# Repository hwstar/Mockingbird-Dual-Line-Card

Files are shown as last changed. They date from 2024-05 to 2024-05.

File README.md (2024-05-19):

# Mockingbird-Dual-Lane-Card
A dual subscriber line card for the Mockingbird Telephone Exchange

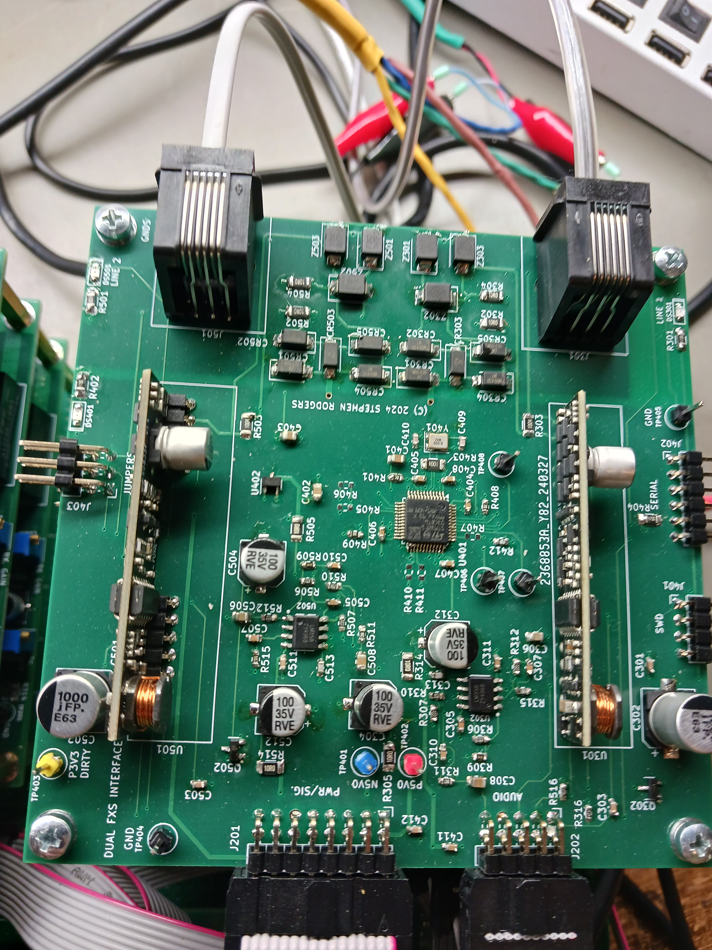
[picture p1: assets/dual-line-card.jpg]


An interface card design for the Mockingbird Telephone Exchange. 

Features: 
* Provides two subscriber line interfaces.
* STM32F103C8T6 microcontroller.
* Accessed from the Main Microcontroller over I2C
* ATTEN signal to main microcontroller to tell it when there is an event to service.
* Audio bandpass filter for the received audio.
* Uses one R-TONE KS0835 SLIC module for each telephone line interface.
* Analog RX audio output, and TX audio input.
* Designed n KiCAD 8.0.

The main project website is on hackaday.io here: https://hackaday.io/project/196044-mockingbird-telephone-exchange

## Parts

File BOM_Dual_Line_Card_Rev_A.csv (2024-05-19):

Item | Part Number | Qty | Reference(s) | Title/Description | Value on Schematic | Manufacturer | Manufacturer Part Number | Footprint
1 | 800063-104 | 15 | C301,C303,C305,C311,C404-C408,C411,C412,C501,C503,C505,C511 | CAP,0603,0.1u,50V,X7R | 0.1u | Kyocera AVX | 06035C104KAT2A | C_0603_1608Metric
1 | 800063-104 | 15 | C301,C303,C305,C311,C404-C408,C411,C412,C501,C503,C505,C511 | CAP,0603,0.1u,50V,X7R | 0.1u | Yageo | CC0603KRX7R9BB104 | C_0603_1608Metric
1 | 800063-104 | 15 | C301,C303,C305,C311,C404-C408,C411,C412,C501,C503,C505,C511 | CAP,0603,0.1u,50V,X7R | 0.1u | LCSC | C14663 | C_0603_1608Metric
2 | 800439-108 | 2 | C302,C502 | CAP,ALUM ELECT,1000UF,6.3V,80 MILLIOHM, 8MM | 1000u | LCSC | C401739 | CP_Elec_8x10.5
2 | 800439-108 | 2 | C302,C502 | CAP,ALUM ELECT,1000UF,6.3V,80 MILLIOHM, 8MM | 1000u | Panasonic | EEEP0J102AP | CP_Elec_8x10.5
3 | 800421-107 | 4 | C304,C312,C504,C512 | CAP,ALUM_ELECT,100uF,35V,ESR 600mOHM,6.3MM,2000 HR | 100u | LCSC | C2836437 | CP_Elec_6.3x7.7
3 | 800421-107 | 4 | C304,C312,C504,C512 | CAP,ALUM_ELECT,100uF,35V,ESR 600mOHM,6.3MM,2000 HR | 100u | KNSCHA | RVE100UF35V67RV0072 | CP_Elec_6.3x7.7
4 | 800423-224 | 2 | C306,C506 | CAP,0805,0.22UF,50V,5%,X7R | 0.22u | Yageo | CC0805JKX7R9BB224 | C_0805_2012Metric
4 | 800423-224 | 2 | C306,C506 | CAP,0805,0.22UF,50V,5%,X7R | 0.22u | LCSC | C520076 | C_0805_2012Metric
5 | 800422-154 | 2 | C307,C507 | CAP,0603,0.15UF,50V,5%,X7R | 0.15u | Yageo | CC0603JRX7R9BB154 | C_0603_1608Metric
5 | 800422-154 | 2 | C307,C507 | CAP,0603,0.15UF,50V,5%,X7R | 0.15u | LCSC | C519580 | C_0603_1608Metric
6 | 800003-106 | 3 | C308,C402,C508 | CAP,0805,10u,25V,X5R | 10u | Murata Electronics | GRM21BR61E106KA73L | C_0805_2012Metric
6 | 800003-106 | 3 | C308,C402,C508 | CAP,0805,10u,25V,X5R | 10u | Samsung Electromechanics | CL21A106KAYNNNE | C_0805_2012Metric
6 | 800003-106 | 3 | C308,C402,C508 | CAP,0805,10u,25V,X5R | 10u | LCSC | C15850 | C_0805_2012Metric
7 | 800422-333 | 2 | C310,C510 | CAP,0603,0.033UF,50V,5%,X7R | 0.033u | YAGEO | CC0603JRX7R9BB333 | C_0603_1608Metric
7 | 800422-333 | 2 | C310,C510 | CAP,0603,0.033UF,50V,5%,X7R | 0.033u | LCSC | C327162 | C_0603_1608Metric
8 | 800002-103 | 2 | C313,C513 | CAP,0603,0.01u,50V,C0G | 0.01u | LCSC | C85973 | C_0603_1608Metric
8 | 800002-103 | 2 | C313,C513 | CAP,0603,0.01u,50V,C0G | 0.01u | Murata Electronics | GRM1885C1H103JA01D | C_0603_1608Metric
9 | 800238-105 | 1 | C401 | CAP,0805,1u,50V,X7R | 1u | WALSIN TECH CORP | 0805B105K500CT | C_0805_2012Metric
9 | 800238-105 | 1 | C401 | CAP,0805,1u,50V,X7R | 1u | Samsung Electromechanics | CL21B105KBFNNNE | C_0805_2012Metric
9 | 800238-105 | 1 | C401 | CAP,0805,1u,50V,X7R | 1u | LCSC | C28323 | C_0805_2012Metric
10 | 800003-226 | 1 | C403 | CAP,0805,22u,25V,X5R | 22u | LCSC | C45783 | C_0805_2012Metric
10 | 800003-226 | 1 | C403 | CAP,0805,22u,25V,X5R | 22u | Samsung Electromechanics | CL21A226MAQNNNE | C_0805_2012Metric
11 | 800002-220 | 2 | C409,C410 | CAP,0603,22p,50V,C0G | 22p | LCSC | C1653 | C_0603_1608Metric
11 | 800002-220 | 2 | C409,C410 | CAP,0603,22p,50V,C0G | 22p | Samsung Electromechanics | CL10C220JB8NNNC | C_0603_1608Metric
12 | 800350-101 | 8 | CR301,CR302,CR304,CR305,CR501,CR502,CR504,CR505 | DIODE,RECTIFIER,GP,1A,1KV,SMA | M7 | LCSC | C95872 | D_SMA
12 | 800350-101 | 8 | CR301,CR302,CR304,CR305,CR501,CR502,CR504,CR505 | DIODE,RECTIFIER,GP,1A,1KV,SMA | M7 | MDD（Microdiode Electronics) | M7 | D_SMA
13 | 800419-750 | 2 | CR303,CR503 | DIODE,TVS,75V,SMA | SMAJ75 | YFW | SMAJ75A | D_SMA
13 | 800419-750 | 2 | CR303,CR503 | DIODE,TVS,75V,SMA | SMAJ75 | LCSC | C2898589 | D_SMA
14 | 800113-102 | 3 | DS301,DS401,DS501 | LED,GREEN,0805 | LEDGRN-SAR | LCSC | C434435 | LED0805
14 | 800113-102 | 3 | DS301,DS401,DS501 | LED,GREEN,0805 | LEDGRN-SAR | Yongsu Photoelectric | SZYY0805YG | LED0805
15 | 800425-116 | 1 | J201 | CONN,HDR,STRIP,DUAL ROW,RA,PTH,2X8,0.254 MM PITCH | Conn_02x08_Odd_Even | LCSC | C2935940 | PinHeader_2x08_P2.54mm_Horizontal
15 | 800425-116 | 1 | J201 | CONN,HDR,STRIP,DUAL ROW,RA,PTH,2X8,0.254 MM PITCH | Conn_02x08_Odd_Even | DEALON | DZ254W-22-16-69 | PinHeader_2x08_P2.54mm_Horizontal
16 | 800425-110 | 1 | J202 | CONN,HDR,STRIP,DUAL ROW,RA,PTH,2X5,0.254 MM PITCH | Conn_02x05_Odd_Even | LCSC | C2935937 | PinHeader_2x05_P2.54mm_Horizontal
16 | 800425-110 | 1 | J202 | CONN,HDR,STRIP,DUAL ROW,RA,PTH,2X5,0.254 MM PITCH | Conn_02x05_Odd_Even | DEALON | DZ254W-22-10-69 | PinHeader_2x05_P2.54mm_Horizontal
17 | 800417-104 | 2 | J301,J501 | CONN_4P4C_CONNFLY | 6P6C | Connfly | DS1133-01-S60BPS | CONN_4P4C_CONNFLY
17 | 800417-104 | 2 | J301,J501 | CONN_4P4C_CONNFLY | 6P6C | LCSC | C77854 | CONN_4P4C_CONNFLY
18 | 800383-104 | 1 | J401 | HEADER,STRIP,RA,4 POS,0.254MM PITCH | CONN4 | DEALON | DZ254W-11-04-65 | PinHeader_1x04_P2.54mm_Horizontal
18 | 800383-104 | 1 | J401 | HEADER,STRIP,RA,4 POS,0.254MM PITCH | CONN4 | LCSC | C2935929 | PinHeader_1x04_P2.54mm_Horizontal
19 | 800383-106 | 1 | J402 | HEADER,STRIP,RA,6 POS,0.254MM PITCH | CONN6 | LCSC | C2935931 | PinHeader_1x06_P2.54mm_Horizontal
19 | 800383-106 | 1 | J402 | HEADER,STRIP,RA,6 POS,0.254MM PITCH | CONN6 | DEALON | DZ254W-11-06-65 | PinHeader_1x06_P2.54mm_Horizontal
20 | 800425-106 | 1 | J403 | CONN,HDR,STRIP,DUAL ROW,RA,PTH,2X3,0.254 MM PITCH | Conn_02x03_Odd_Even | LCSC | C2935935 | PinHeader_2x03_P2.54mm_Horizontal
20 | 800425-106 | 1 | J403 | CONN,HDR,STRIP,DUAL ROW,RA,PTH,2X3,0.254 MM PITCH | Conn_02x03_Odd_Even | DEALON | DZ254W-22-06-69 | PinHeader_2x03_P2.54mm_Horizontal
21 | 800346-101 | 2 | Q302,Q502 | XSTR,MOSFET,SOT-23,N-CH,60V,115MA | 2N7002 | LCSC | C8545 | SOT-23-3
21 | 800346-101 | 2 | Q302,Q502 | XSTR,MOSFET,SOT-23,N-CH,60V,115MA | 2N7002 | JIANGSU CHANGJIANG ELECTRONICS TECHNOLOGY CO LTD. | 2N7002 | SOT-23-3
22 | 800057-471 | 4 | R301,R402,R404,R501 | RES,1206,470 OHM,1%,1/4W | 470 | LCSC | C4502 | R_1206_3216Metric
22 | 800057-471 | 4 | R301,R402,R404,R501 | RES,1206,470 OHM,1%,1/4W | 470 | Uni-Royal | 1206W4F4700T5E | R_1206_3216Metric
23 | 800057-100 | 8 | R302,R304,R305,R314,R502,R504,R505,R514 | RES,1206,10 OHM,1%,1/4W | 10 | LCSC | C844016 | R_1206_3216Metric
23 | 800057-100 | 8 | R302,R304,R305,R314,R502,R504,R505,R514 | RES,1206,10 OHM,1%,1/4W | 10 | Vishay | CRCW120610R0FKEB | R_1206_3216Metric
24 | 800057-105 | 3 | R303,R403,R503 | RES,1206,1M OHM,1%,1/4W | 1M | Uni-Royal | 1206W4F1004T5E | R_1206_3216Metric
24 | 800057-105 | 3 | R303,R403,R503 | RES,1206,1M OHM,1%,1/4W | 1M | LCSC | C17927 | R_1206_3216Metric
25 | 800022-220 | 6 | R306,R307,R312,R506,R507,R512 | RES,0603,2.2K OHM,1% | 2.2K | LCSC | C4190 | R_0603_1608Metric
25 | 800022-220 | 6 | R306,R307,R312,R506,R507,R512 | RES,0603,2.2K OHM,1% | 2.2K | Uni-Royal | 0603WAF2201T5E | R_0603_1608Metric
26 | 800022-150 | 2 | R309,R509 | RES,0603,1.50K OHM,1%,E24 | 1.5K | LCSC | C25804 | R_0603_1608Metric
26 | 800022-150 | 2 | R309,R509 | RES,0603,1.50K OHM,1%,E24 | 1.5K | Uni-Royal | 0603WAF1002T5E | R_0603_1608Metric
27 | 800022-300 | 2 | R310,R510 | RES,0603,3.0K OHM,1%,E24 | 3K | Resistor.Today | AECR0603F3K00K9 | R_0603_1608Metric
27 | 800022-300 | 2 | R310,R510 | RES,0603,3.0K OHM,1%,E24 | 3K | Uni-Royal | 0603WAF3001T5E | R_0603_1608Metric
27 | 800022-300 | 2 | R310,R510 | RES,0603,3.0K OHM,1%,E24 | 3K | LCSC | C4211 | R_0603_1608Metric
28 | 800021-100 | 2 | R311,R511 | RES,0603,100 OHM,1% | 100 | LCSC | C22775,C2759451 | R_0603_1608Metric
28 | 800021-100 | 2 | R311,R511 | RES,0603,100 OHM,1% | 100 | Uni-Royal | 0603WAF1000T5E | R_0603_1608Metric
29 | 800022-680 | 2 | R315,R515 | RES,0603,6.8K OHM,1%,E24 | 6.8K | LCSC | C23212 | R_0603_1608Metric
29 | 800022-680 | 2 | R315,R515 | RES,0603,6.8K OHM,1%,E24 | 6.8K | Uni-Royal | 0603WAF6801T5E | R_0603_1608Metric
30 | 800023-470 | 2 | R316,R516 | RES,0603,47K OHM,1% | 47K | LCSC | C25819 | R_0603_1608Metric
30 | 800023-470 | 2 | R316,R516 | RES,0603,47K OHM,1% | 47K | Uni-Royal | 0603WAF4702T5E | R_0603_1608Metric
31 | 800023-100 | 3 | R401,R408,R409 | RES,0603,10.0K OHM,1% | 10K | WALSIN TECH CORP | MR06X1002FTL | R_0603_1608Metric
31 | 800023-100 | 3 | R401,R408,R409 | RES,0603,10.0K OHM,1% | 10K | Uni-Royal | 0603WAF1002T5E | R_0603_1608Metric
31 | 800023-100 | 3 | R401,R408,R409 | RES,0603,10.0K OHM,1% | 10K | LCSC | C25804 | R_0603_1608Metric
32 | 800020-000 | 3 | R407,R410,R411 | RES,0603,0 OHM,1%,E24 | 0 | LCSC | C21189 | R_0603_1608Metric
32 | 800020-000 | 3 | R407,R410,R411 | RES,0603,0 OHM,1%,E24 | 0 | Uni-Royal | 0603WAF0000T5E | R_0603_1608Metric
33 | 800020-330 | 1 | R412 | RES,0603,33 OHM,1%,E24 | 33 | Uni-Royal | 0603WAF330JT5E | R_0603_1608Metric
33 | 800020-330 | 1 | R412 | RES,0603,33 OHM,1%,E24 | 33 | LCSC | C23140 | R_0603_1608Metric
34 | 800418-101 | 2 | U301,U501 | MODULE_SLIC,RINGING | KS0835F | R-TONE | KS0835F | SLIC_MODULE_KS0835
35 | 800379-101 | 2 | U302,U502 | IC,OP-AMP,GP,DUAL,SOIC8 | LM358 | LCSC | C7950 | SOIC8N-SAR
35 | 800379-101 | 2 | U302,U502 | IC,OP-AMP,GP,DUAL,SOIC8 | LM358 | Texas Instruments | LM358D | SOIC8N-SAR
35 | 800379-101 | 2 | U302,U502 | IC,OP-AMP,GP,DUAL,SOIC8 | LM358 | On Semiconductor | LM358DR2G | SOIC8N-SAR
36 | 800405-101 | 1 | U401 | IC,MPU,ARM CORTEX M3,64KB,LQFP-48 | STM32F103C4Tx | LCSC | C8734 | LQFP-48_7x7mm_P0.5mm
36 | 800405-101 | 1 | U401 | IC,MPU,ARM CORTEX M3,64KB,LQFP-48 | STM32F103C4Tx | ST Microelectronics | STM32F103C8T6 | LQFP-48_7x7mm_P0.5mm
37 | 800187-101 | 1 | U402 | IC,VREG,LDO,500MA,3.3V,SOT23 | ME6211A33M3G-N | Nanjing Micro One Elec | ME6211A33M3B-N | SOT23-3-SAR-V2
37 | 800187-101 | 1 | U402 | IC,VREG,LDO,500MA,3.3V,SOT23 | ME6211A33M3G-N | LCSC | C168807 | SOT23-3-SAR-V2
38 | 800412-008 | 1 | Y401 | CRYSTAL,8MHZ,12PF,10PPM,SMT,3225 | 8.0M | LCSC | C5308003 | Crystal_SMD_3225-4Pin_3.2x2.5mm
38 | 800412-008 | 1 | Y401 | CRYSTAL,8MHZ,12PF,10PPM,SMT,3225 | 8.0M | Shenzhen Yajingxin Electron Co.,Ltd | TX32258M4FBDD2T | Crystal_SMD_3225-4Pin_3.2x2.5mm
39 | 800424-350 | 6 | Z301-Z303,Z501-Z503 | SURGE SUPPRESSOR, THYRISTOR, 350V, SMB | P3100SC | LCSC | C2901314 | D_SMB
39 | 800424-350 | 6 | Z301-Z303,Z501-Z503 | SURGE SUPPRESSOR, THYRISTOR, 350V, SMB | P3100SC | Tech Public | P3100SC | D_SMB
40 | XXXXXX-XXX | 0 |  | DNI | DNI | DNI | DNI | DNI

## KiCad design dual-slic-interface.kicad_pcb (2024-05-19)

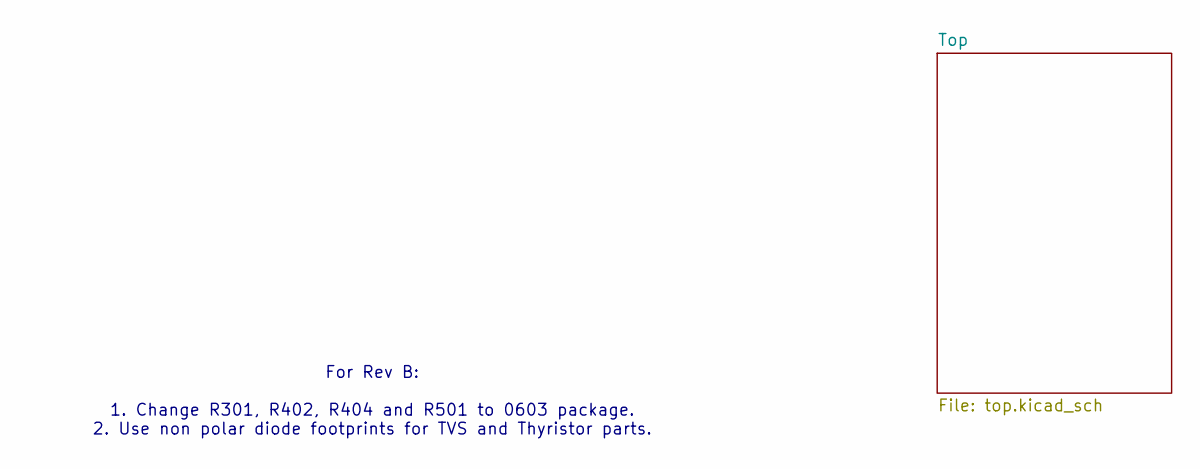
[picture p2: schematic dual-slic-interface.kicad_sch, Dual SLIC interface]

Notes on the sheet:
For Rev B: 1. Change R301, R402, R404 and R501 to 0603 package. 2. Use non polar diode footprints for TVS and Thyristor parts.

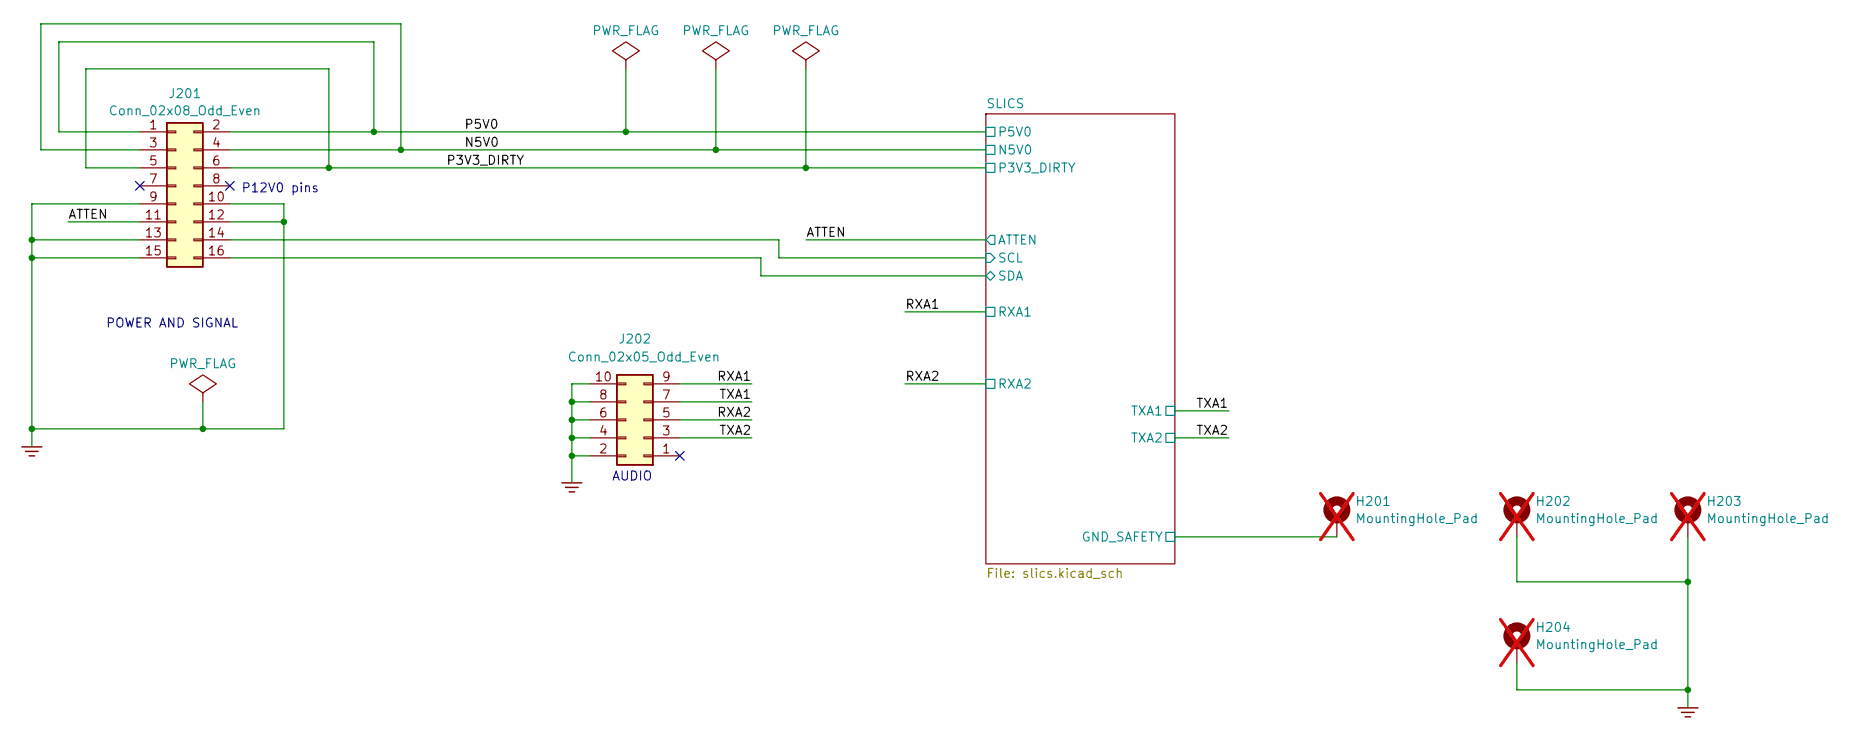
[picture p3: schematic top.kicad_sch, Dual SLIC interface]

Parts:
H201, H202, H203, H204: MountingHole_Pad; MountingHole_3.2mm_M3_Pad_Via; PartNumber 800XXX-XXX; not fitted
J201: Conn_02x08_Odd_Even; PinHeader_2x08_P2.54mm_Horizontal; PartNumber 800425-116
J202: Conn_02x05_Odd_Even; PinHeader_2x05_P2.54mm_Horizontal; PartNumber 800425-110

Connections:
/Top/ATTEN: J201.11; also elsewhere on the board
/Top/N5V0: J201.3, J201.4; also elsewhere on the board
/Top/P3V3_DIRTY: J201.5, J201.6; also elsewhere on the board
/Top/P5V0: J201.1, J201.2; also elsewhere on the board
/Top/RXA1: J202.9; also elsewhere on the board
/Top/RXA2: J202.5; also elsewhere on the board
/Top/SLICS/SCL: J201.14; also elsewhere on the board
/Top/SLICS/SDA: J201.16; also elsewhere on the board
/Top/SLICS/slic/GND_SAFETY: H201.1; also elsewhere on the board
/Top/TXA1: J202.7; also elsewhere on the board
/Top/TXA2: J202.3; also elsewhere on the board
GND: H202.1, H203.1, H204.1, J201.9, J201.10, J201.12, J201.13, J201.15, J202.2, J202.4, J202.6, J202.8, J202.10; also elsewhere on the board

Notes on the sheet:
AUDIO
POWER AND SIGNAL
P12V0 pins

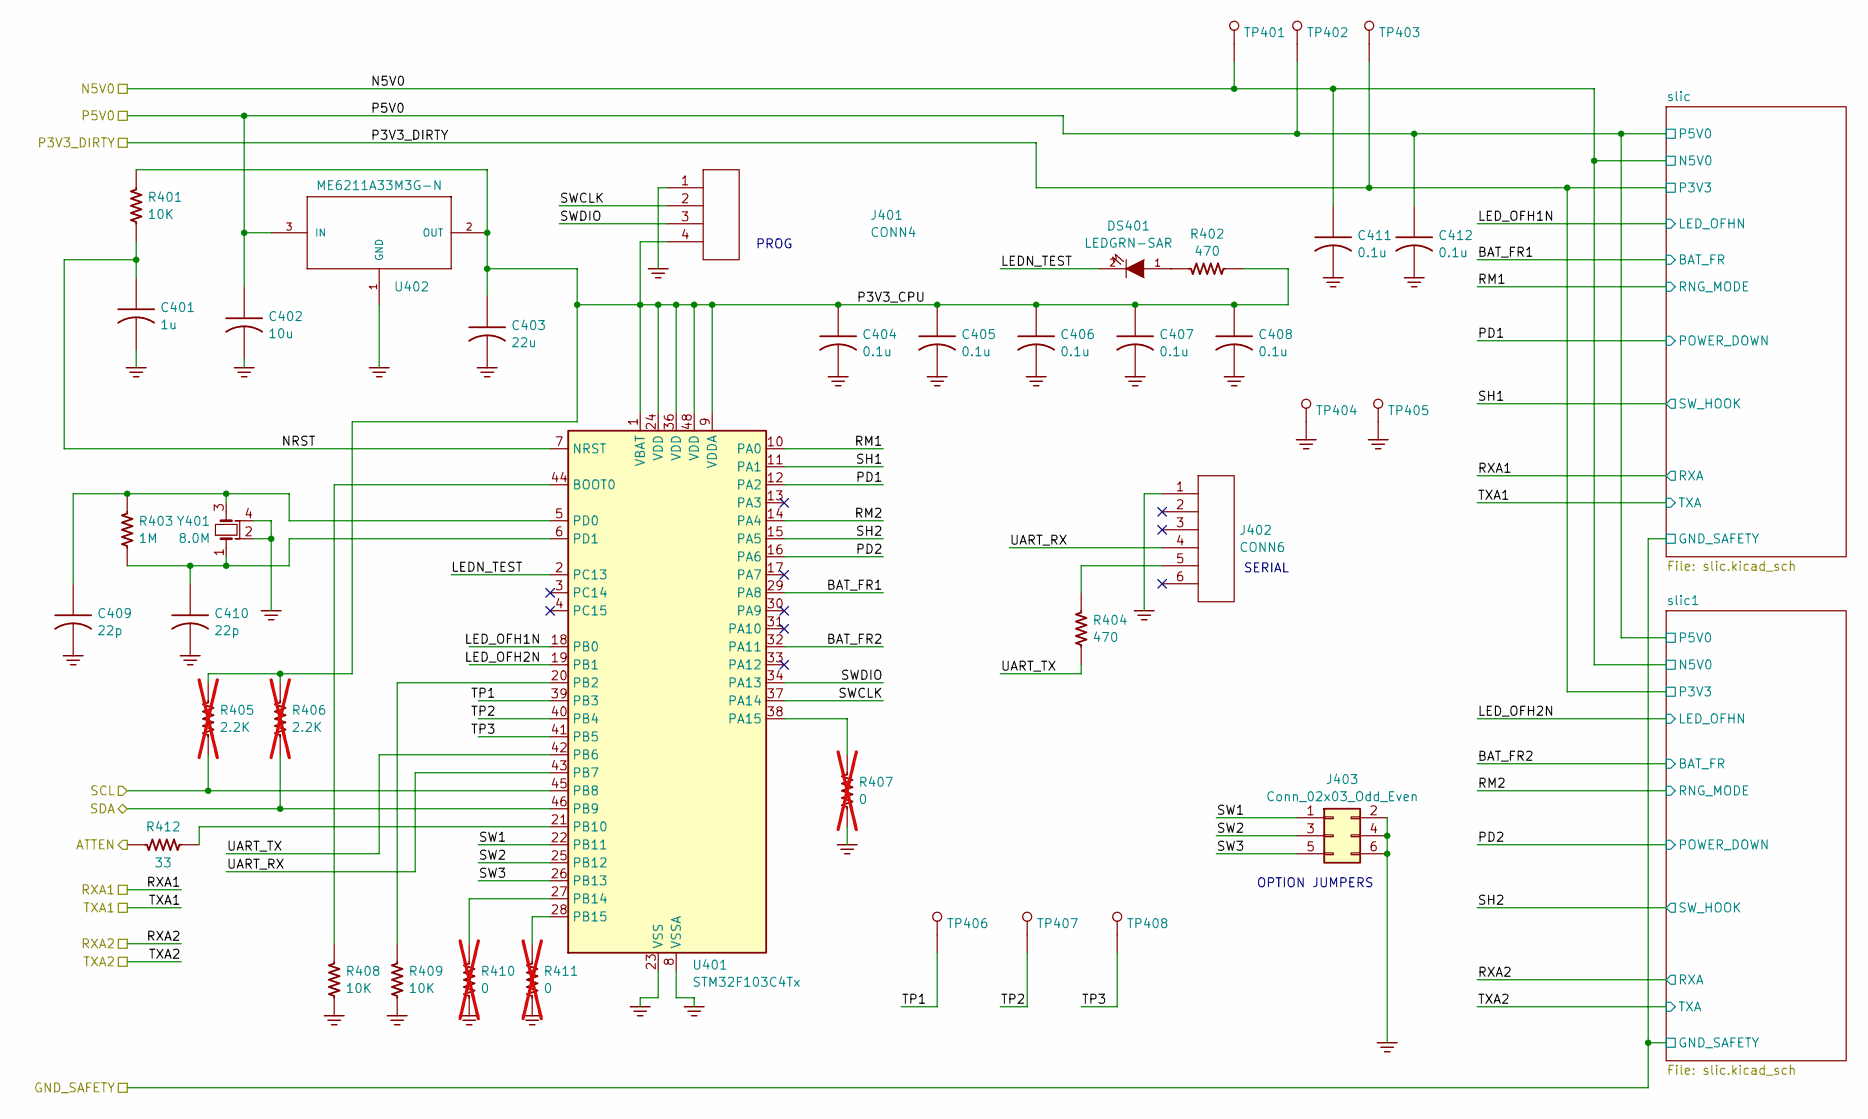
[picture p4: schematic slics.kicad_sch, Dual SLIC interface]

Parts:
C401: 1u; C_0805_2012Metric; PartNumber 800238-105
C402: 10u; C_0805_2012Metric; PartNumber 800003-106
C403: 22u; C_0805_2012Metric; PartNumber 800003-226
C404, C405, C406, C407, C408, C411, C412: 0.1u; C_0603_1608Metric; PartNumber 800063-104
C409, C410: 22p; C_0603_1608Metric; PartNumber 800002-220
DS401: LEDGRN-SAR; LED0805; PartNumber 800113-102
J401: CONN4; PinHeader_1x04_P2.54mm_Horizontal; PartNumber 800383-104
J402: CONN6; PinHeader_1x06_P2.54mm_Horizontal; PartNumber 800383-106
J403: Conn_02x03_Odd_Even; PinHeader_2x03_P2.54mm_Horizontal; PartNumber 800425-106
R401, R408, R409: 10K; R_0603_1608Metric; PartNumber 800023-100
R402, R404: 470; R_1206_3216Metric; PartNumber 800057-471
R403: 1M; R_1206_3216Metric; PartNumber 800057-105
R405, R406: 2.2K; R_0603_1608Metric; PartNumber 800022-220; not fitted
R407, R410, R411: 0; R_0603_1608Metric; PartNumber 800020-000; not fitted
R412: 33; R_0603_1608Metric; PartNumber 800020-330
TP401, TP402, TP403, TP404, TP405, TP406, TP407, TP408: TESTPINTPSQ025; TESTPIN
U401: STM32F103C4Tx; LQFP-48_7x7mm_P0.5mm; PartNumber 800405-101
U402: ME6211A33M3G-N; SOT23-3-SAR-V2; PartNumber 800187-101
Y401: 8.0M; Crystal_SMD_3225-4Pin_3.2x2.5mm; PartNumber 800412-008

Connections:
/Top/ATTEN: R412.1; also elsewhere on the board
/Top/N5V0: C411.1, TP401.1 (TP); also elsewhere on the board
/Top/P3V3_DIRTY: TP403.1 (TP); also elsewhere on the board
/Top/P5V0: C402.1, C412.1, TP402.1 (TP), U402.3 (IN); also elsewhere on the board
/Top/SLICS/BAT_FR1: U401.29 (PA8); also elsewhere on the board
/Top/SLICS/BAT_FR2: U401.32 (PA11); also elsewhere on the board
/Top/SLICS/LEDN_TEST: DS401.2 (K), U401.2 (PC13)
/Top/SLICS/LED_OFH1N: U401.18 (PB0); also elsewhere on the board
/Top/SLICS/LED_OFH2N: U401.19 (PB1); also elsewhere on the board
/Top/SLICS/NRST: C401.1, R401.2, U401.7 (NRST)
/Top/SLICS/P3V3_CPU: C403.1, C404.1, C405.1, C406.1, C407.1, C408.1, J401.4, R401.1, R402.2, R405.1, R406.1, U401.1 (VBAT), U401.9 (VDDA), U401.24 (VDD), U401.36 (VDD), U401.48 (VDD), U402.2 (OUT)
/Top/SLICS/PD1: U401.12 (PA2); also elsewhere on the board
/Top/SLICS/PD2: U401.16 (PA6); also elsewhere on the board
/Top/SLICS/RM1: U401.10 (PA0); also elsewhere on the board
/Top/SLICS/RM2: U401.14 (PA4); also elsewhere on the board
/Top/SLICS/SCL: R405.2, U401.45 (PB8); also elsewhere on the board
/Top/SLICS/SDA: R406.2, U401.46 (PB9); also elsewhere on the board
/Top/SLICS/SH1: U401.11 (PA1); also elsewhere on the board
/Top/SLICS/SH2: U401.15 (PA5); also elsewhere on the board
/Top/SLICS/SW1: J403.1, U401.22 (PB11)
/Top/SLICS/SW2: J403.3, U401.25 (PB12)
/Top/SLICS/SW3: J403.5, U401.26 (PB13)
/Top/SLICS/SWCLK: J401.2, U401.37 (PA14)
/Top/SLICS/SWDIO: J401.3, U401.34 (PA13)
/Top/SLICS/TP1: TP406.1 (TP), U401.39 (PB3)
/Top/SLICS/TP2: TP407.1 (TP), U401.40 (PB4)
/Top/SLICS/TP3: TP408.1 (TP), U401.41 (PB5)
/Top/SLICS/UART_RX: J402.4, U401.43 (PB7)
/Top/SLICS/UART_TX: R404.2, U401.42 (PB6)
GND: C401.2, C402.2, C403.2, C404.2, C405.2, C406.2, C407.2, C408.2, C409.2, C410.2, C411.2, C412.2, J401.1, J402.1, J403.2, J403.4, J403.6, R407.2, R408.2, R409.2, R410.2, R411.2, TP404.1 (TP), TP405.1 (TP), U401.8 (VSSA), U401.23 (VSS), U401.35 (VSS), U401.47 (VSS), U402.1 (GND), Y401.2, Y401.4 (2); also elsewhere on the board
unnamed: DS401.1 (A), R402.1
unnamed: J402.5, R404.1
unnamed: R408.1, U401.44 (BOOT0)
unnamed: R407.1, U401.38 (PA15)
unnamed: R409.1, U401.20 (PB2)
unnamed: R412.2, U401.21 (PB10)
unnamed: R410.1, U401.27 (PB14)
unnamed: R411.1, U401.28 (PB15)
unnamed: C409.1, R403.1, U401.5 (PD0), Y401.3
unnamed: C410.1, R403.2, U401.6 (PD1), Y401.1

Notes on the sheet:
SERIAL
OPTION JUMPERS
PROG

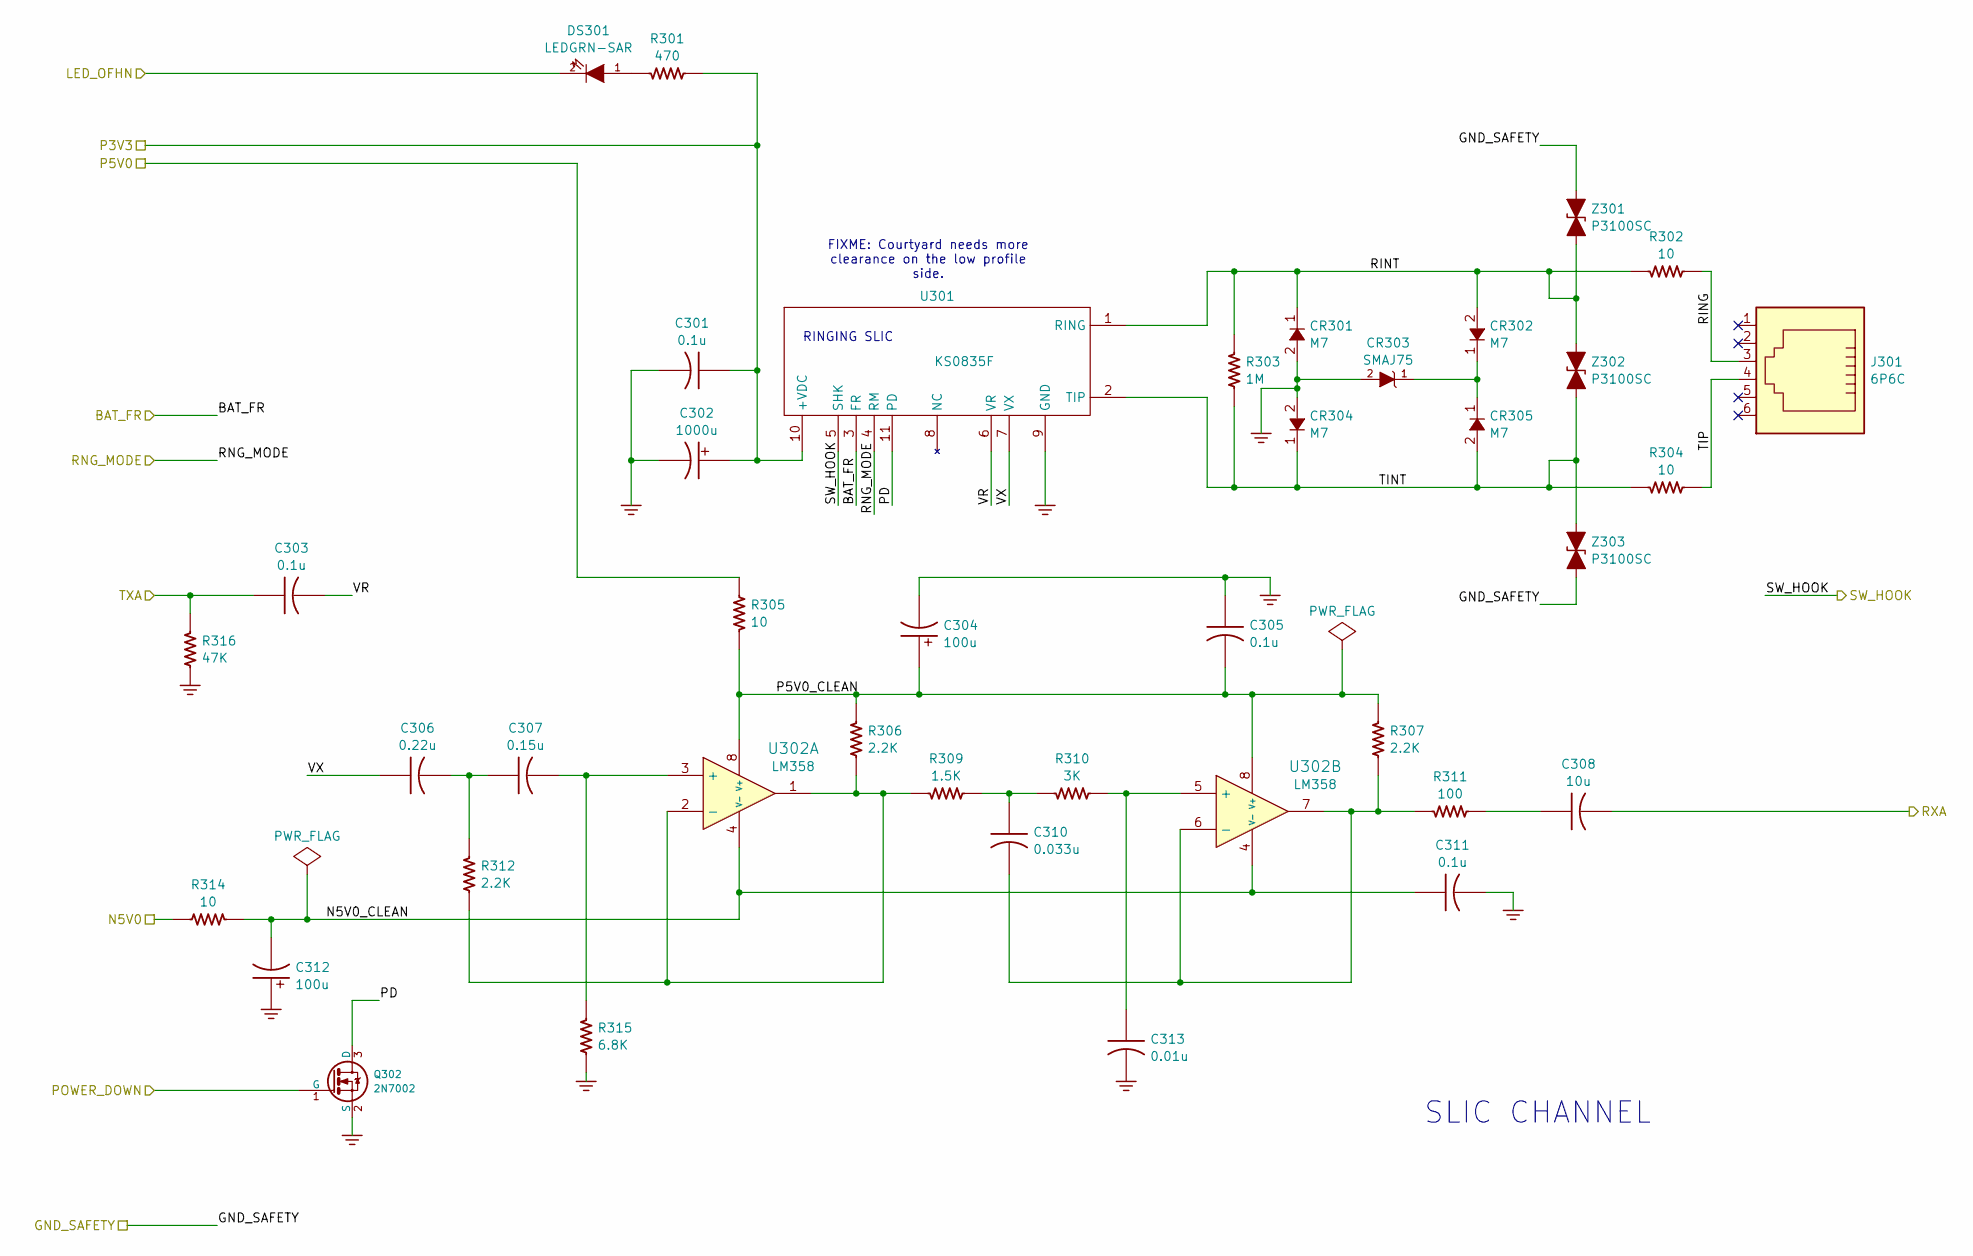
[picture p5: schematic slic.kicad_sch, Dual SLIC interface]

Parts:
C301, C303, C305, C311: 0.1u; C_0603_1608Metric; PartNumber 800063-104
C302: 1000u; CP_Elec_8x10.5; PartNumber 800439-108
C304, C312: 100u; CP_Elec_6.3x7.7; PartNumber 800421-107
C306: 0.22u; C_0805_2012Metric; PartNumber 800423-224
C307: 0.15u; C_0603_1608Metric; PartNumber 800422-154
C308: 10u; C_0805_2012Metric; PartNumber 800003-106
C310: 0.033u; C_0603_1608Metric; PartNumber 800422-333
C313: 0.01u; C_0603_1608Metric; PartNumber 800002-103
CR301, CR302, CR304, CR305: M7; D_SMA; PartNumber 800350-101
CR303: SMAJ75; D_SMA; PartNumber 800419-750
DS301: LEDGRN-SAR; LED0805; PartNumber 800113-102
J301: 6P6C; CONN_4P4C_CONNFLY; PartNumber 800417-104
Q302: 2N7002; SOT-23-3; PartNumber 800346-101
R301: 470; R_1206_3216Metric; PartNumber 800057-471
R302, R304, R305, R314: 10; R_1206_3216Metric; PartNumber 800057-100
R303: 1M; R_1206_3216Metric; PartNumber 800057-105
R306, R307, R312: 2.2K; R_0603_1608Metric; PartNumber 800022-220
R309: 1.5K; R_0603_1608Metric; PartNumber 800022-150
R310: 3K; R_0603_1608Metric; PartNumber 800022-300
R311: 100; R_0603_1608Metric; PartNumber 800021-100
R315: 6.8K; R_0603_1608Metric; PartNumber 800022-680
R316: 47K; R_0603_1608Metric; PartNumber 800023-470
U301: KS0835F; SLIC_MODULE_KS0835; PartNumber 800418-101
U302: LM358; SOIC8N-SAR; PartNumber 800379-101
Z301, Z302, Z303: P3100SC; D_SMB; PartNumber 800424-350

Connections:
/Top/N5V0: R314.2; also elsewhere on the board
/Top/P3V3_DIRTY: C301.1, C302.1, R301.2, U301.10 (+VDC); also elsewhere on the board
/Top/P5V0: R305.2; also elsewhere on the board
/Top/RXA1: C308.2; also elsewhere on the board
/Top/SLICS/BAT_FR1: U301.3 (FR); also elsewhere on the board
/Top/SLICS/LED_OFH1N: DS301.2 (K); also elsewhere on the board
/Top/SLICS/PD1: Q302.1 (G); also elsewhere on the board
/Top/SLICS/RM1: U301.4 (RM); also elsewhere on the board
/Top/SLICS/SH1: U301.5 (SHK); also elsewhere on the board
/Top/SLICS/slic/GND_SAFETY: Z301.2 (A2), Z303.1 (A1); also elsewhere on the board
/Top/SLICS/slic/N5V0_CLEAN: C311.1, C312.2, R314.1, U302.4 (V-)
/Top/SLICS/slic/P5V0_CLEAN: C304.1, C305.2, R305.1, R306.1, R307.1, U302.8 (V+)
/Top/SLICS/slic/PD: Q302.3 (D), U301.11 (PD)
/Top/SLICS/slic/RING: J301.3, R302.2
/Top/SLICS/slic/RINT: CR301.1 (K), CR302.2 (A), R302.1, R303.1, U301.1 (RING), Z301.1 (A1), Z302.2 (A2)
/Top/SLICS/slic/TINT: CR304.1 (K), CR305.2 (A), R303.2, R304.1, U301.2 (TIP), Z302.1 (A1), Z303.2 (A2)
/Top/SLICS/slic/TIP: J301.4, R304.2
/Top/SLICS/slic/VR: C303.2, U301.6 (VR)
/Top/SLICS/slic/VX: C306.1, U301.7 (VX)
/Top/TXA1: C303.1, R316.1; also elsewhere on the board
GND: C301.2, C302.2, C304.2, C305.1, C311.2, C312.1, C313.2, CR301.2 (A), CR303.2 (A), CR304.2 (A), Q302.2 (S), R315.2, R316.2, U301.9 (GND); also elsewhere on the board
unnamed: C306.2, C307.1, R312.1
unnamed: C308.1, R311.2
unnamed: C310.1, R309.2, R310.1
unnamed: CR302.1 (K), CR303.1 (K), CR305.1 (K)
unnamed: DS301.1 (A), R301.1
unnamed: C307.2, R315.1, U302.3 (+)
unnamed: R306.2, R309.1, R312.2, U302.1, U302.2 (-)
unnamed: C313.1, R310.2, U302.5 (+)
unnamed: C310.2, R307.2, R311.1, U302.6 (-), U302.7

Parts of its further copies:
C501, C503, C505, C511: 0.1u; C_0603_1608Metric; PartNumber 800063-104
C502: 1000u; CP_Elec_8x10.5; PartNumber 800439-108
C504, C512: 100u; CP_Elec_6.3x7.7; PartNumber 800421-107
C506: 0.22u; C_0805_2012Metric; PartNumber 800423-224
C507: 0.15u; C_0603_1608Metric; PartNumber 800422-154
C508: 10u; C_0805_2012Metric; PartNumber 800003-106
C510: 0.033u; C_0603_1608Metric; PartNumber 800422-333
C513: 0.01u; C_0603_1608Metric; PartNumber 800002-103
CR501, CR502, CR504, CR505: M7; D_SMA; PartNumber 800350-101
CR503: SMAJ75; D_SMA; PartNumber 800419-750
DS501: LEDGRN-SAR; LED0805; PartNumber 800113-102
J501: 6P6C; CONN_4P4C_CONNFLY; PartNumber 800417-104
Q502: 2N7002; SOT-23-3; PartNumber 800346-101
R501: 470; R_1206_3216Metric; PartNumber 800057-471
R502, R504, R505, R514: 10; R_1206_3216Metric; PartNumber 800057-100
R503: 1M; R_1206_3216Metric; PartNumber 800057-105
R506, R507, R512: 2.2K; R_0603_1608Metric; PartNumber 800022-220
R509: 1.5K; R_0603_1608Metric; PartNumber 800022-150
R510: 3K; R_0603_1608Metric; PartNumber 800022-300
R511: 100; R_0603_1608Metric; PartNumber 800021-100
R515: 6.8K; R_0603_1608Metric; PartNumber 800022-680
R516: 47K; R_0603_1608Metric; PartNumber 800023-470
U501: KS0835F; SLIC_MODULE_KS0835; PartNumber 800418-101
U502: LM358; SOIC8N-SAR; PartNumber 800379-101
Z501, Z502, Z503: P3100SC; D_SMB; PartNumber 800424-350

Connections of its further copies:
/Top/N5V0: R514.2; also elsewhere on the board
/Top/P3V3_DIRTY: C501.1, C502.1, R501.2, U501.10 (+VDC); also elsewhere on the board
/Top/P5V0: R505.2; also elsewhere on the board
/Top/RXA2: C508.2; also elsewhere on the board
/Top/SLICS/BAT_FR2: U501.3 (FR); also elsewhere on the board
/Top/SLICS/LED_OFH2N: DS501.2 (K); also elsewhere on the board
/Top/SLICS/PD2: Q502.1 (G); also elsewhere on the board
/Top/SLICS/RM2: U501.4 (RM); also elsewhere on the board
/Top/SLICS/SH2: U501.5 (SHK); also elsewhere on the board
/Top/SLICS/slic1/N5V0_CLEAN: C511.1, C512.2, R514.1, U502.4 (V-)
/Top/SLICS/slic1/P5V0_CLEAN: C504.1, C505.2, R505.1, R506.1, R507.1, U502.8 (V+)
/Top/SLICS/slic1/PD: Q502.3 (D), U501.11 (PD)
/Top/SLICS/slic1/RING: J501.3, R502.2
/Top/SLICS/slic1/RINT: CR501.1 (K), CR502.2 (A), R502.1, R503.1, U501.1 (RING), Z501.1 (A1), Z502.2 (A2)
/Top/SLICS/slic1/TINT: CR504.1 (K), CR505.2 (A), R503.2, R504.1, U501.2 (TIP), Z502.1 (A1), Z503.2 (A2)
/Top/SLICS/slic1/TIP: J501.4, R504.2
/Top/SLICS/slic1/VR: C503.2, U501.6 (VR)
/Top/SLICS/slic1/VX: C506.1, U501.7 (VX)
/Top/SLICS/slic/GND_SAFETY: Z501.2 (A2), Z503.1 (A1); also elsewhere on the board
/Top/TXA2: C503.1, R516.1; also elsewhere on the board
GND: C501.2, C502.2, C504.2, C505.1, C511.2, C512.1, C513.2, CR501.2 (A), CR503.2 (A), CR504.2 (A), Q502.2 (S), R515.2, R516.2, U501.9 (GND); also elsewhere on the board
unnamed: C506.2, C507.1, R512.1
unnamed: C508.1, R511.2
unnamed: C510.1, R509.2, R510.1
unnamed: CR502.1 (K), CR503.1 (K), CR505.1 (K)
unnamed: DS501.1 (A), R501.1
unnamed: C507.2, R515.1, U502.3 (+)
unnamed: R506.2, R509.1, R512.2, U502.1, U502.2 (-)
unnamed: C513.1, R510.2, U502.5 (+)
unnamed: C510.2, R507.2, R511.1, U502.6 (-), U502.7

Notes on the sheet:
SLIC CHANNEL
RINGING SLIC
FIXME: Courtyard needs more clearance on the low profile side.

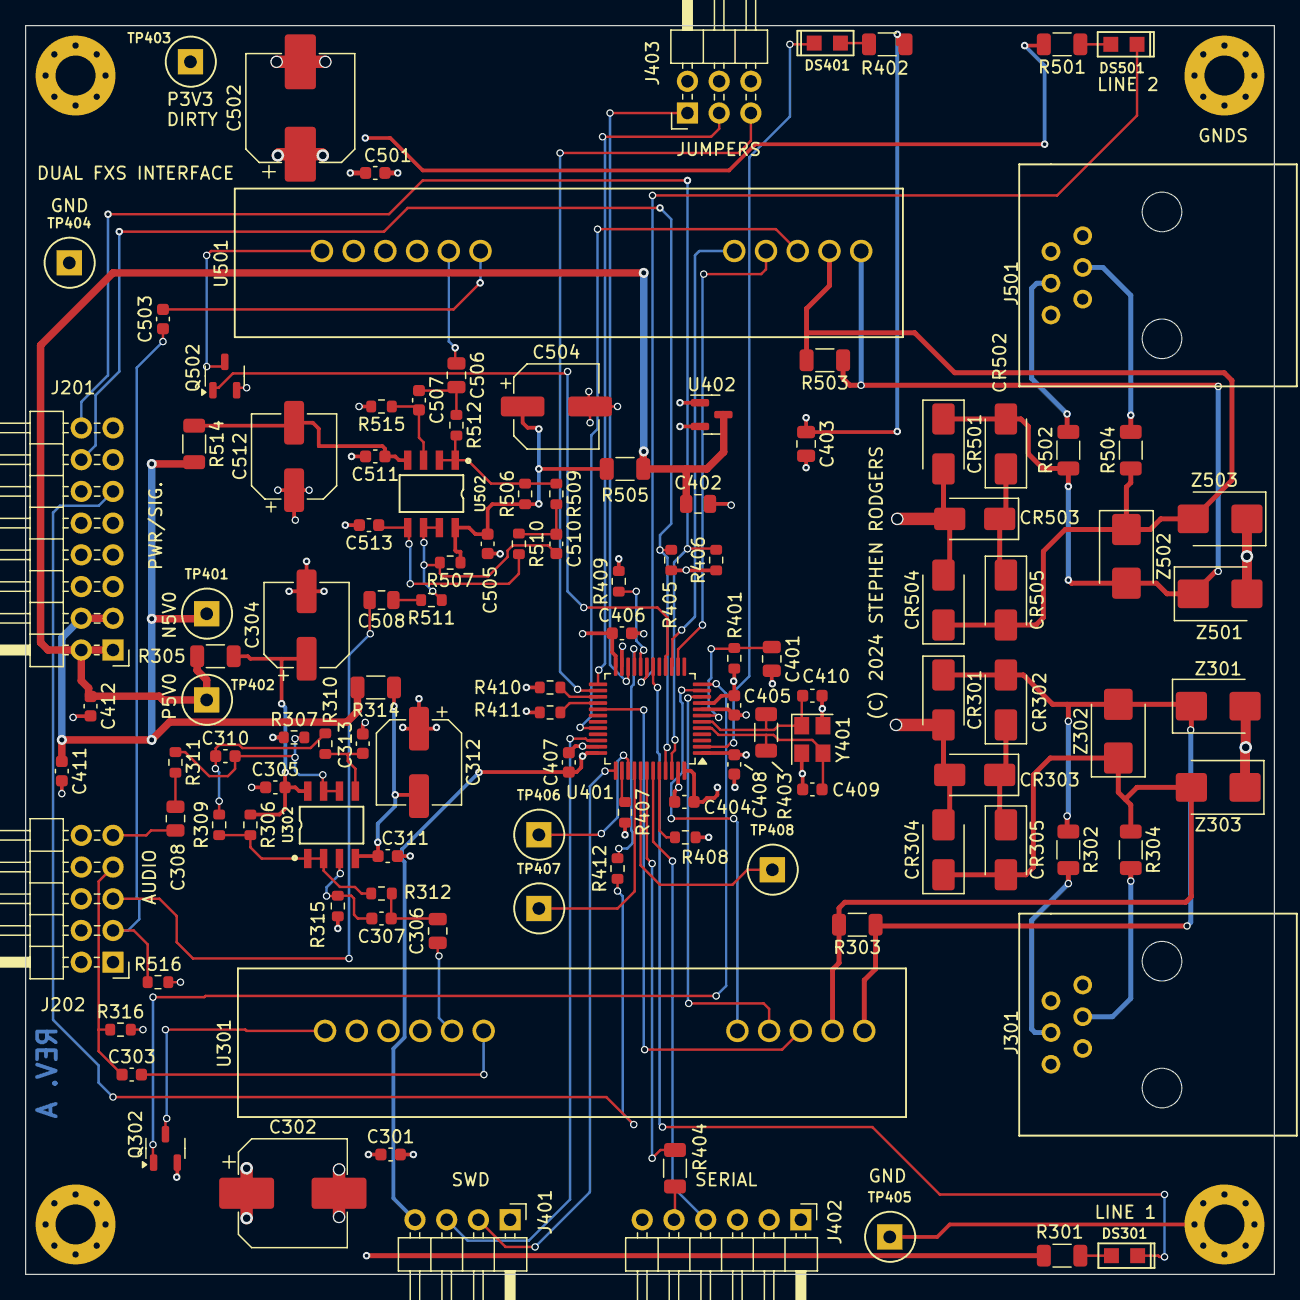
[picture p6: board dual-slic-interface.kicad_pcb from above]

Board: 4 copper layers, 100.0 x 100.0 mm, 123 parts (0 on the bottom side), 81 nets.

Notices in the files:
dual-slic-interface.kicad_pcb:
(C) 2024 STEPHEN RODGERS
